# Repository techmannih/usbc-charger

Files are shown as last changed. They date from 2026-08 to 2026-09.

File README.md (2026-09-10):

# USB-C PD 18 W AC Wall Charger

This repository contains the electrical and PCB design for an isolated AC-mains to USB-C Power Delivery charger. Written in tscircuit, the design accepts a nominal 100–240 VAC input and supports three negotiated output profiles: 5 V / 3 A, 9 V / 2 A, and 12 V / 1.5 A, up to 18 W.

The design combines mains protection, EMI filtering, an encapsulated AC/DC module, a USB-PD buck stage, secondary-side transient protection, PCB layout, and a mechanical fit-check enclosure in one TypeScript project.

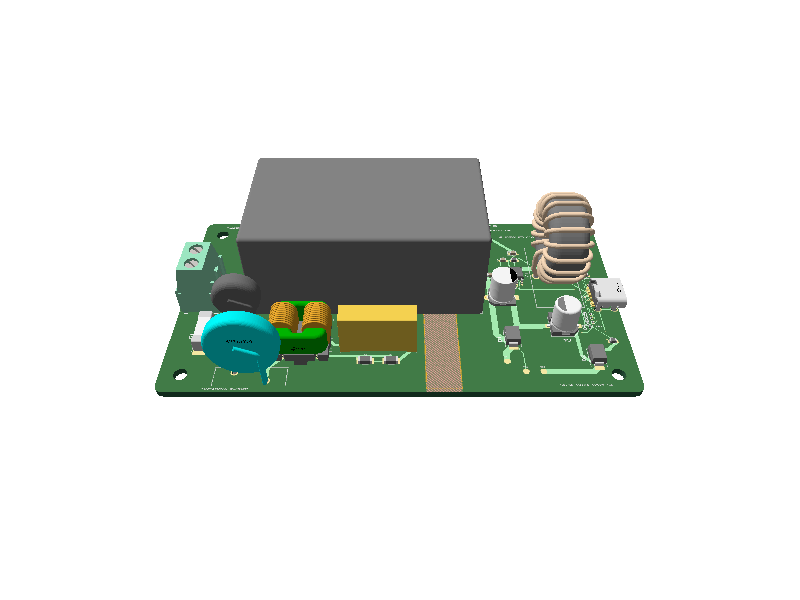
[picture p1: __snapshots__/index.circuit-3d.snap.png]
3D view of the assembled charger PCB


## At a glance

| Item | Specification |
| --- | --- |
| Product input rating | 100–240 VAC, 50/60 Hz |
| AC/DC module operating range | 85–265 VAC |
| USB-C output profiles | 5 V / 3 A, 9 V / 2 A, 12 V / 1.5 A |
| Maximum USB output | 18 W |
| Isolated supply | HLK-20M15C, 15 V / 1.333 A |
| USB-PD buck SoC | Standard Injoinic IP6520 (non-PPS) |
| PCB | 110 × 60 mm, 2-layer, 1.6 mm FR-4 |
| Isolation layout | 8 mm primary-to-SELV all-layer copper keepout |
| Enclosure model | 116 × 66 × 42 mm fit-check shell |
| Firmware | None; the selected IP6520 handles PD negotiation and output selection autonomously |

This implementation uses the standard `IP6520` (`C7433861`) non-PPS variant and is not a USB-C input/sink design. Other IP6520 family variants provide different output profiles and are not approved BOM substitutions.

## Power architecture

```text
AC line / neutral
  │
  ├─ F1      2 A time-delay fuse
  ├─ RV1     300 VAC MOV surge clamp
  ├─ TH1     5 Ω NTC inrush limiter
  ├─ LCM1    two-line common-mode choke
  ├─ C7      305 VAC X2 capacitor with R3/R4 bleeders
  │
  └─ U1      HLK-20M15C isolated 15 V AC/DC module
       │
       ├─ D1 15 V rail TVS
       │
       └─ U2 IP6520 synchronous buck + USB-PD source
            ├─ L1/C4/C5 output power stage
            ├─ D2 USB VBUS TVS
            ├─ D3–D6 CC and USB 2.0 ESD protection
            │
            └─ J2 USB-C output
                 ├─ 5 V / 3 A
                 ├─ 9 V / 2 A
                 └─ 12 V / 1.5 A
```

### Mains input and filtering

The AC input enters through `J1`. The line conductor is protected by a time-delay fuse, MOV, and NTC before passing through the common-mode choke. A safety-rated X2 capacitor filters line-to-neutral noise, while two series bleeder resistors discharge it after disconnection.

The filtered mains input feeds the encapsulated `HLK-20M15C`. Using a bought-out isolated module keeps the carrier board focused on input protection, physical separation, and the low-voltage USB-PD stage instead of implementing a custom offline flyback converter.

### Isolated USB-PD output

The module's isolated 15 V output is locally bypassed and protected by `D1`. The `IP6520` then performs synchronous buck conversion and USB-PD source negotiation. Its switch node drives a 22 µH inductor, output capacitors, and the USB-C VBUS rail.

The USB side includes a dedicated VBUS TVS, individual low-capacitance clamps for CC1, CC2, D+, and D−, and test points for 15 V, ground, and VBUS measurements.

### Power and validation margin

The `HLK-20M15C` is nominally rated for 15 V at 1.333 A. Buck-conversion losses leave little electrical and thermal headroom while delivering the full 18 W USB output. Full-load efficiency, input-current, regulation, and temperature-rise testing in the final closed enclosure are mandatory before retaining the 18 W rating.

The IP6520 input range includes 15 V, but the datasheet's 12 V / 1.5 A electrical-characteristic point is specified with a 24 V input. The exact 15 V input to 12 V / 1.5 A output condition therefore remains a hardware-validation point. If the board cannot sustain it across mains, load, temperature, and transient limits, the 12 V PDO must be removed/derated or the power architecture revised.

## PCB and mechanical design

- Primary-side AC parts are grouped on the left; the isolated USB-PD stage is on the right.
- An 8 mm copper-free corridor spans both copper layers between the primary and SELV regions.
- The ground pour is restricted to the isolated low-voltage side.
- Routed trace widths and via dimensions are recorded in the fabrication geometry report.
- Four 3.2 mm non-plated mounting holes provide fixed enclosure mounting points.
- The USB-C receptacle and mains entry include enclosure aperture definitions.
- The included FDM enclosure is a volume and connector-alignment model, not a production housing.

PCB and schematic snapshots are available in [`__snapshots__/`](__snapshots__). The standalone enclosure fit-check model is in [`mechanical/enclosure-fit-check.scad`](mechanical/enclosure-fit-check.scad).

## Key components

| Ref | Part | Function | JLCPCB/LCSC |
| --- | --- | --- | --- |
| J1 | WJ500V-5.08-2P | AC line/neutral termination | C8465 |
| F1 | SCT1032T2A250V | 2 A / 250 V time-delay fuse | C19712562 |
| RV1 | Bourns MOV-14D471K | 300 VAC surge suppression | C1527439 |
| TH1 | MF72 5D9 | 5 Ω / 3 A inrush limiter | C11277 |
| LCM1 | XRSQ1010-10mH-H | 10 mH two-line common-mode choke | C5380257 |
| C7 | TDK B32922C3104M189 | 100 nF / 305 VAC class-X2 capacitor | C125429 |
| R3, R4 | 1206W4F1004T5E | Series X-capacitor bleeders | C17927 |
| U1 | Hi-Link HLK-20M15C | Isolated 15 V / 1.333 A AC/DC module | C52746093 |
| D1 | SMBJ15A | 15 V rail TVS | C83846 |
| U2 | Injoinic IP6520 | Synchronous buck + USB-PD source SoC; standard non-PPS variant | C7433861 |
| L1 | PDMTAT068125-220MLU | 22 µH buck inductor | C3011539 |
| D2 | SMBJ13A | USB VBUS TVS | C19077567 |
| D3–D6 | PESD5V0H1BSF | CC and USB 2.0 ESD protection | C477989 |
| J2 | TYPE-C-31-M-12 | USB-C receptacle | C165948 |

The supplier IDs are included for design reproducibility, not as an approval of substitutions or a guarantee of stock. Verify the exact manufacturer, rating, footprint, and safety documentation before assembly. In particular, confirm that U2 is marked and ordered as the standard `IP6520`; do not substitute another family variant without requalifying the USB-PD profiles and power budget.

## Repository structure

```text
.
├── index.circuit.tsx              Main tscircuit source and board layout
├── index.circuit.circuit.json     Generated circuit consumed by viewers/tools
├── imports/                       Custom component and footprint definitions
├── firmware/                      Autonomous-controller profile and host PDO checker
├── fabrication/                   BOM, CPL, Gerbers, pin map, drawings and check records
├── scripts/                       Reproducible export and fabrication-integrity checks
├── .github/workflows/             Independent GitHub circuit CI
├── BOM.csv                        Generated complete purchased electrical BOM
├── __snapshots__/                 Schematic, PCB, and 3D reference renders
├── mechanical/                    Enclosure fit-check source
├── FABRICATION_NOTES.md            Board construction and CAM review notes
├── FIRMWARE_BRINGUP.md             Controller/board bring-up; no flashing required
├── PINMAP.md                      Important interfaces and full generated pin-map link
├── POWER_BUDGET.md                Calculated conversion and module headroom
├── JLCPCB_PARTS.md                 Procurement and assembly-list guidance
├── PACKAGE_AUDIT.md                Package and supplier orientation review scope
├── DESIGN_REVIEW.md                Review index and open findings
├── VALIDATION.md                   Reproduction commands and check scope
├── DRC_REPORT.md                   CAD findings and retained-log index
├── COMPLIANCE_PLAN.md             Certification planning and evidence gaps
├── LAB_VALIDATION_PLAN.md         Hardware test plan
├── ENCLOSURE_REQUIREMENTS.md      Production enclosure requirements
└── DESIGN_RISK_REGISTER.md        Known risks and release gates
```

## Getting started

The project uses [Bun](https://bun.sh/) and the tscircuit CLI included in the development dependencies.

```sh
git clone https://github.com/techmannih/usbc-charger.git
cd usbc-charger
bun install
bun run dev
```

`bun run dev` opens the interactive tscircuit development viewer. The default circuit entrypoint is [`index.circuit.tsx`](index.circuit.tsx).

## Commands

| Command | Purpose |
| --- | --- |
| `bun run dev` | Start the interactive local viewer |
| `bun run typecheck` | Check the TypeScript source |
| `bun run check:netlist` | Check declared circuit connections |
| `bun run build` | Build `dist/index/circuit.json` with routing and the parts engine disabled |
| `bun run build:placement` | Alias for the default placement build |
| `bun run build:routed` | Build with full routing, bypassing the placement config; 5-minute timeout per autorouter phase |
| `bun run verify` | Run type, netlist, schematic placement, PCB placement, shorts, and build checks |
| `bun run build:preview` | Generate PCB, schematic, and 3D preview images |
| `bun run snapshot:update` | Update committed PCB, schematic, and 3D snapshots |
| `bun run snapshot:3d:update` | Update the committed angled 3D snapshot |
| `bun run build:handoff` | Generate KiCad, STEP, and GLB handoff outputs |
| `bun run export:fabrication` | Fresh build, check records, BOM/CPL/pinmap, both schematic sheets and gated Gerber export |
| `bun run check:fabrication` | Verify generated artifacts, BOM/placement coverage, archive contents and source hashes |
| `bun run check:pdos <capture.json>` | Compare decoded analyzer PDOs with the design targets; no device flashing |

Generated export files are written under `dist/index/`.

`tscircuit.config.json` disables routing for the default build, including hosted
builds that read this config. Use `bun run build:routed` for routed output.
CI, `verify`, handoff builds, and fabrication exports explicitly enable routing.

The dedicated fabrication workflow writes a versioned review package under
[`fabrication/`](fabrication/README.md), plus the root [`BOM.csv`](BOM.csv).
It requires Bun and `zip`/`unzip`. Its source inventory and file hashes prevent
accidental mixing of revisions. See
[`REFERENCE_COMPARISON.md`](fabrication/REFERENCE_COMPARISON.md) for the file-category
mapping to the three linked pedometer projects.

The controller needs no external application firmware. The new
[`firmware/`](firmware/README.md) folder records the expected fixed PDOs and
contains a host-side capture checker. It cannot change U2's behavior.

## Development workflow

Use a topic branch and open a pull request into `main`, with a descriptive
commit/PR title such as `ci: add circuit build checks`. The
[`Circuit CI`](.github/workflows/circuit-ci.yml) workflow runs on pull requests
into `main`, pushes to `main`, and manual dispatches. It provides three checks:
`Typecheck`, `Netlist`, and `Build`. Build waits for both other checks, verifies
the committed fabrication package, compiles the circuit, then checks the fresh
routed output for copper shorts. Build outputs and any short-check diagnostics
are retained as a workflow artifact for seven days.

CI uses Bun 1.3.14 from `packageManager`, SHA-pinned actions, a frozen lockfile,
and read-only repository permissions. It does not publish to tscircuit, push
commits, or approve manufacturing. Existing placement-review findings remain
documented in [`DRC_REPORT.md`](DRC_REPORT.md); this workflow is not the full
`bun run verify` release gate. To enforce checks before merge, configure the
three check names as required in GitHub branch rules after their first run.

The package version is `1.0.10`, which was unused in the tscircuit registry when
checked on September 10, 2026. Hosted `1.0.9` already belongs to commit `6e64034`;
the integration skips a different commit that reuses that release version.
Use an unused version when pushing the next hosted release.

The `1.0.9` hosted build completed with exit code 0 and uploaded its outputs,
but its GitHub `tscircuit/build` status was absent. The later `dabd400` push was
accepted by the webhook but produced no new release. A version bump addresses
the release collision; missing GitHub status updates require a separate check
of tscircuit's integration permissions and server-side status-update logs.
Verify both the release commit and the GitHub status after pushing to `main`
(or merging a PR). A passing `Circuit CI` result alone does not establish either.

Regenerate `bun run export:fabrication` and run `bun run check:fabrication`
after changing files covered by the fabrication manifest, including
`package.json`, documentation, or export scripts; commit the refreshed outputs
with those changes.

After changing the circuit source or a component definition:

```sh
bun run verify
bun run snapshot:update
bun run snapshot:3d:update
git diff -- index.circuit.circuit.json __snapshots__
```

Commit `index.circuit.circuit.json` whenever the TSX circuit changes. Hosted viewers and downstream tools can consume this generated file; leaving it stale can make a deployed board differ from the local `tsci dev` render.

Before opening a hardware or manufacturing handoff, inspect the schematic, PCB, 3D assembly, generated circuit JSON, and check outputs together.

## Design status

The repository contains the CAD source and engineering workflow for a hardware prototype. It is not a validated or certified consumer product. Automated CAD checks establish source consistency; they do not prove electrical safety, EMC performance, thermal margin, enclosure safety, or USB-IF compliance.

The remaining physical work includes:

- prototype assembly and incoming-part verification;
- USB-PD protocol and load testing across every supported PDO;
- efficiency, ripple, thermal-rise, and abnormal-condition testing;
- surge, EFT, ESD, conducted/radiated emissions, and immunity testing;
- creepage, clearance, dielectric-strength, leakage, and accessible-part evaluation;
- validation inside the final flame-retardant enclosure with the production cord and strain relief.

See the project handoff documents for detailed requirements:

- [`COMPLIANCE_PLAN.md`](COMPLIANCE_PLAN.md)
- [`LAB_VALIDATION_PLAN.md`](LAB_VALIDATION_PLAN.md)
- [`ENCLOSURE_REQUIREMENTS.md`](ENCLOSURE_REQUIREMENTS.md)
- [`DESIGN_RISK_REGISTER.md`](DESIGN_RISK_REGISTER.md)

## Safety notice

This board contains hazardous mains voltage. Do not energize an exposed PCB, connect it to a phone, or treat the fit-check enclosure as a finished product. Mains testing and enclosure review must be performed with appropriate equipment by qualified personnel.

The final product requires verified safety-critical parts, a rated cable and plug, independent strain relief, inaccessible live parts, preserved creepage and clearance, a suitable flame-retardant enclosure, and approval under the standards applicable to the target market.

## Design references

- [Hi-Link HLK-20M15C product page](https://www.hlktech.net/index.php?cateid=734&id=128)
- [Injoinic IP6520 datasheet](https://www.injoinic.com/api/static/uploads/20250529/20250529105252_6837cc049d55b.pdf)
- [TDK B32922C3104M189 X2 capacitor](https://product.tdk.com/en/search/capacitor/film/emi-suppression/info?part_no=B32922C3104M189)
- [Bourns MOV-14D series datasheet](https://www.bourns.com/docs/Product-Datasheets/MOV14D.pdf)
- [USB-IF USB Type-C and USB Power Delivery](https://www.usb.org/usbc)
- [USB-IF compliance program](https://www.usb.org/compliance)
- [BIS products under compulsory registration](https://www.bis.gov.in/product-certification/products-under-compulsory-certification/scheme-ii-registration-scheme/)

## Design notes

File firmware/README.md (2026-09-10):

# Firmware and controller configuration

This board has no programmable microcontroller, external flash, SWD/JTAG header,
UART console or I²C configuration interface. U2 is the standard non-PPS IP6520
power-conversion/PD source controller. No application binary needs to be built
or flashed for this hardware revision. The pedometer references use an MCU,
BLE and sensors; their firmware cannot run on this charger.

[`expected-pdos.json`](expected-pdos.json) records the design targets from the
main schematic and the exact U2 ordering variant. Editing it does not change
the controller's output behavior. Changing advertised PDOs requires a reviewed
controller/variant or hardware change, followed by hardware verification.

## Files

| File | Purpose |
| --- | --- |
| `expected-pdos.json` | Expected 5 V / 3 A, 9 V / 2 A and 12 V / 1.5 A fixed PDOs |
| `check-pdos.mjs` | Host-side check of decoded protocol-analyzer records |
| `VALIDATION.md` | Software-check scope and hardware evidence status |
| `../FIRMWARE_BRINGUP.md` | Board bring-up, interfaces and observation points |

## Check a protocol capture

Export/decode the analyzer's Source_Capabilities message and map it to this JSON
schema. This is a schema example, not a measured capture; replace the metadata
and PDO values with the actual observation. Keep the original analyzer log.

```json
{
  "schema_version": 1,
  "sample_id": "REPLACE_WITH_ASSEMBLED_SAMPLE_ID",
  "analyzer": "REPLACE_WITH_ANALYZER_MODEL_AND_SERIAL",
  "captured_at": "2026-09-10T00:00:00Z",
  "evidence_file": "REPLACE_WITH_ORIGINAL_ANALYZER_LOG_PATH",
  "source_capabilities": [
    { "type": "fixed", "voltage_v": 5, "current_a": 3 },
    { "type": "fixed", "voltage_v": 9, "current_a": 2 },
    { "type": "fixed", "voltage_v": 12, "current_a": 1.5 }
  ]
}
```

```sh
bun run check:pdos /path/to/capture.json
```

The checker requires the three exact PDOs in the order shown and rejects extra
PDOs/APDOs, wrong types, missing metadata and wrong advertised current/voltage.
It checks the supplied decoded record; it does not authenticate the evidence
file, connect to an analyzer, measure VBUS, test regulation or certify USB-PD.

Reference: [Injoinic IP6520 datasheet linked by this design](https://www.injoinic.com/api/static/uploads/20250529/20250529105252_6837cc049d55b.pdf).
Confirm the standard variant's ordering table; the family contains different
PPS and power-profile variants.

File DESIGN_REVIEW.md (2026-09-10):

# Design review

The current implementation is an 18 W, two-layer isolated mains charger with
an HLK-20M15C 15 V supply and standard non-PPS IP6520 output controller.
The reference pedometers provide examples of repository organization; their
BLE, battery-charger, sensor, MCU and RF design details do not apply here.

## Review artifacts

| Review area | Evidence / document |
| --- | --- |
| Architecture, ratings and source | `README.md`, `index.circuit.tsx` |
| Pin/net correspondence | `PINMAP.md`, `fabrication/PINMAP.csv`, `fabrication/netlist.txt` |
| Procurement and assembly | `BOM.csv`, `JLCPCB_PARTS.md`, fabrication BOM/CPL/manual list |
| Package/centroid verification | `PACKAGE_AUDIT.md`, `fabrication/placement-review.csv` |
| Output power and thermal headroom | `POWER_BUDGET.md`, `DESIGN_RISK_REGISTER.md` |
| Controller bring-up | `FIRMWARE_BRINGUP.md`, `firmware/` |
| Automated CAD validation | `VALIDATION.md`, `DRC_REPORT.md`, `fabrication/checks/` |
| Construction and physical tests | Existing compliance, enclosure and lab plans |

## Open findings

The design needs measured verification at 18 W, especially 12 V / 1.5 A from
the 15 V module rail. Supplier orientation/centroid calibration and a physical
footprint audit remain open. The existing placement checker reports orientation
suggestions for C6, D5 and D6; schematic placement also reports readability
suggestions. Their exact outputs are retained with the package.

The fabrication workflow checks routed copper separately from source
connectivity and records source hashes so files from different revisions can
be detected. It keeps the existing hardware validation gates visible and does
not turn a successful CAD check into a production release.

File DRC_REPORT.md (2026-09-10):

# CAD check report

Authoritative results for the current exported artifact are in
[`fabrication/validation.json`](fabrication/validation.json) and
[`fabrication/checks/`](fabrication/checks/). Regenerate them after source changes.

The initial assessment for this file-package addition found:

- netlist check: no errors or warnings;
- routed-circuit checks: no findings;
- Gerber-derived shorts check: no detected shorts;
- PCB placement: three suboptimal-orientation suggestions (C6, D5, D6),
  with zero placement DRC errors/warnings; the command exits 1 for the suggestions;
- schematic placement: existing orientation/trace-simplification suggestions;
- build: succeeds with existing courtyard, chip pin-specification and
  schematic-reference diagnostics.

The build's reference-text warnings include built-in symbols whose labels are
drawn by the renderer. Both schematic sheets are exported for visual review.
Warnings are retained in `checks/build.log`, not silently counted as passes.

These findings do not constitute supplier CAM or physical clearance approval.
The export gate requires no routed-artifact errors and a passing copper-shorts
check. The manifest remains `released_for_manufacturing: false` until the
separate design, assembly and hardware release process is completed.

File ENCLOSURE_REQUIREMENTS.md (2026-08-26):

# Production enclosure requirements

The `enclosure.fdm.box` in the circuit is a 116 × 66 × 42 mm fit-check shell. It is suitable for checking connector alignment and board volume only. Do not use a hobby FDM print as the consumer mains enclosure.

The production mechanical design must be reviewed with the safety lab and should include:

- a certified/traceable flame-retardant insulating resin and process appropriate to the applicable standard, with material documentation retained per production lot;
- no user-accessible primary conductor, terminal, screw, solder joint or mounting hardware under accessibility probes and expected deformation;
- a rated two-core mains lead and plug for the destination market, with double-insulated internal wiring and a listed cable gland/strain relief sized to the real cord;
- independent cord anchorage so a pull or twist cannot load J1 or reduce primary-to-SELV spacing;
- insulating ribs/barriers and standoff geometry that preserve required creepage/clearance after assembly tolerances, solder protrusion, impact and heat;
- captive/secure board retention using the four 3.2 mm non-plated holes without conductive hardware bridging insulation zones;
- a USB-C opening that cannot expose internal live parts and does not mechanically overload J2;
- ventilation only if the lab accepts it; openings must still pass accessibility and fire-containment requirements;
- tamper-resistant closure, adequate impact strength and no service access for ordinary users;
- permanent external ratings, model/serial traceability, indoor-use/safety markings and certification identifiers only after authorization.

## Mechanical release checks

- Import the actual PCB STEP output and exact bought-out connector/cord models into production CAD.
- Apply dimensional, molding/shrink and assembly tolerance stacks to apertures, standoffs and insulation barriers.
- Verify assembly sequence, no pinched wires, strain-relief engagement, fastener torque and repeatable connector location.
- Conduct thermal testing in the real color, resin, wall thickness and closed configuration; the fit-check shell is not a thermal surrogate.
- Freeze the enclosure drawing, resin grade, molder/process and cord assembly as certification-controlled items.

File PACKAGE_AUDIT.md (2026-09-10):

# Footprint and package audit

This document identifies package checks for the current imports. It records
the review scope; it is not a completed manufacturer-drawing audit.

| Parts | Source / check |
| --- | --- |
| U1 | `imports/HLK_20M15C.tsx`: module pin numbering, 15 V polarity, body and lead clearance |
| U2 | `imports/IP6520.tsx`: ESOP8/EP pin 9, exposed-pad dimensions and thermal-via process |
| J1 | `imports/WJ500V_5_08_2P.tsx`: 5.08 mm terminals, AC neutral alias, cable access |
| J2 | `imports/TYPE_C_31_M_12.tsx`: 16 selectors, duplicated contacts, SMT land pattern, plated slots and NPTH locating holes |
| LCM1 | `imports/XRSQ1010_10mH_H.tsx`: winding pairs, four lead positions and full body outline |
| L1 | `imports/PDMTAT068125_220MLU.tsx`: actual through-hole package and body orientation |
| C7 | `imports/B32922C3104M189.tsx`: lead spacing and safety-rated body |
| C1/C4 | Imported SMT can footprints: pin-1 polarity and supplier centroid |
| D1/D2 | Imported SMB packages: cathode pad and diode orientation |
| D3–D6 | Imported tiny ESD package: land sizes, pad spacing, stencil and rotation |
| Small R/C parts | Built-in 0603/1206 footprints: land pattern versus exact purchased part |
| F1/RV1/TH1 | Imported footprints: body size, pad/lead form, heat and clearance requirements |

The source carries MPN/supplier IDs, footprint geometry and 3D-model URLs. A
model URL or successful render is not proof that the physical part matches.
Compare manufacturer package drawings with pads, hole dimensions, pin map,
body/courtyard and mechanical fit. Record differences before approving changes.

Generated [`geometry.json`](fabrication/geometry.json) and
[`placement-review.csv`](fabrication/placement-review.csv) support this review.
STEP/GLB models can be regenerated using `bun run build:handoff`; inspect any
reported missing-model downloads separately.

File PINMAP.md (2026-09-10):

# Pin and interface map

The complete map is generated at [`fabrication/PINMAP.csv`](fabrication/PINMAP.csv)
from the same circuit JSON used for the manufacturing review exports. It
includes aliases, physical pad coordinates, layer sets and intentional NCs.

## U2: standard IP6520

| Pin | Signal | Board net |
| --- | --- | --- |
| 1 | VOUT | VBUS_OUT |
| 2 | VIN | VIN_15V |
| 3 | SW | SW |
| 4 | BST | BST |
| 5 | DM | USB_DM |
| 6 | DP | USB_DP |
| 7 | CC1 | CC1 |
| 8 | CC2 | CC2 |
| 9 | Exposed pad / GND | GND |

## U1: isolated module

| Pin | Signal | Board net |
| --- | --- | --- |
| 1 | AC2 | AC_N_FILTERED |
| 2 | AC1 | AC_L_FILTERED |
| 3 | VNEG | GND |
| 4 | VPOS | VIN_15V |

## J2: USB-C connector

The import numbers 1–16 are footprint selectors, not USB Type-C contact names.
Use the aliases in PINMAP.csv: pin 6 = A5/CC1, pin 12 = B5/CC2;
pins 8/10 = A6/B6/D+, pins 9/7 = A7/B7/D−;
pins 15/16 = B4A9/A4B9/VBUS, pins 13/14 = A1B12/B1A12/GND.
Pins 1–4 are shield tabs. Pins 5/11 (B8/A8, SBU2/SBU1) are intentionally NC.

J1 pin 2 has the imported alias `GND` but belongs to **AC_N**. It is not
connected to the isolated low-voltage ground. TP1, TP2 and TP3 are respectively
VIN_15V, isolated GND and VBUS_OUT.

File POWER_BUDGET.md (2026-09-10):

# Power budget

These calculations use the design's nominal U1 rating of 15 V × 1.333 A =
19.995 W. They are estimates, not measured efficiency or thermal results.

| USB fixed PDO target | Output power | U1 current at 90% buck efficiency | U1 current at 95% buck efficiency |
| --- | --- | --- | --- |
| 5 V / 3 A | 15 W | 1.111 A | 1.053 A |
| 9 V / 2 A | 18 W | 1.333 A | 1.263 A |
| 12 V / 1.5 A | 18 W | 1.333 A | 1.263 A |

`I_U1 = P_USB / (15 V × buck efficiency)`. At 18 W, a nominal 90% conversion
efficiency consumes essentially all of the module's rated output. Even at
95%, only about 1.05 W remains at the module output before accounting for
derating and other losses. Required conversion efficiency at the nominal
module limit is about `18 / 19.995 = 90.02%`.

The input/EMI losses and U1 AC/DC losses add heat and affect overall wall-to-USB
efficiency. They are not included in the buck-only calculation above. Thermal
derating can further reduce the usable 19.995 W module rating.

At the 12 V PDO, nominal input-to-output voltage difference is only 3 V. Verify
dropout, ripple and load transients at the actual minimum 15 V rail. The
datasheet electrical-characteristic point for 12 V / 1.5 A uses 24 V input, so
it is not evidence of measured performance for this board's 15 V input.

## Measurements to retain

Record AC input power, U1 rail voltage/current, USB voltage/current, ambient,
steady-state temperatures and enclosure revision at each PDO and declared
input extreme. Use [`LAB_VALIDATION_PLAN.md`](LAB_VALIDATION_PLAN.md) for the
test scope. No thermal or efficiency measurements have been supplied.

The project name's historic `20w` directory does not change the implemented
18 W target. Exact controller identity and target profiles are in
[`firmware/expected-pdos.json`](firmware/expected-pdos.json).

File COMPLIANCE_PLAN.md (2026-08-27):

# Compliance plan

Status: engineering-validation design; no certification, registration, licence, TID or logo authorization has been obtained.

This plan must be frozen against the exact PCB revision, BOM, firmware/silicon revision, mains cord/plug and final enclosure submitted to the labs. A change to any safety-critical item can require review or retest.

## Intended product definition

- External Class II power adaptor for IT/consumer equipment.
- Label input: 100–240 VAC, 50/60 Hz. The AC/DC module's 85–265 VAC figure is an operating range, not the proposed consumer label range.
- USB-C source PDOs: 5 V/3 A, 9 V/2 A and 12 V/1.5 A; 18 W maximum; exact standard IP6520 non-PPS variant.
- No protective-earth connection.
- Final construction: closed, touch-safe, flame-retardant enclosure with a rated mains cord/plug and strain relief.

## Workstream matrix

| Workstream | Design evidence available | Required independent evidence before sale |
| --- | --- | --- |
| India electrical safety | Isolated module architecture, fused/protected input, primary/SELV keepout, controlled BOM | BIS-recognized lab report and registration for the final adaptor under the classification/standard confirmed by BIS; construction, dielectric, temperature and abnormal-condition results |
| International electrical safety | Hazard-based design provisions and component documentation | Accredited evaluation to the applicable market edition, commonly IEC 62368-1 or its national adoption; national deviations and marking review |
| USB Type-C/PD | Standard non-PPS IP6520 reference topology and fixed-supply PDO intent | USB-IF-authorized lab execution of every applicable Type-C and PD CTS section; valid TID/listing before using certified USB claims or logos |
| EMC/immunity | CMC, X2 capacitor, local bypassing, short power loops and port ESD parts | Conducted/radiated emissions and applicable ESD, EFT, surge, dips/interruptions and immunity tests on the final closed product |
| Energy efficiency | Low-power topology selected | Applicable market efficiency/no-load measurements and declarations for external power supplies |
| Materials/mechanics | Mounting holes and fit-check enclosure model | Resin flammability evidence, touch-access/probe tests, impact/drop, cord anchorage, torque, heat/ball-pressure and enclosure construction review |
| Production conformity | Exact MPNs and supplier numbers recorded | Approved-vendor list, incoming inspection, traceability, calibrated end-of-line tests and controlled change process |

## India submission package

Prepare at minimum:

- final schematic, PCB artwork/stack-up, critical-component list and BOM;
- component certificates/datasheets for the AC/DC module, fuse, MOV, X2 capacitor, PCB laminate, enclosure resin, connector and mains lead/plug;
- photographs and construction drawings showing insulation barriers, spacings, internal wiring, strain relief and markings;
- product label artwork, model/series declaration and user safety instructions;
- risk assessment, abnormal-condition rationale and production test procedure;
- samples that exactly match the declared PCB, enclosure and critical BOM.

India's current BIS material lists “Power Adaptors for IT Equipments” under IS 13252 (Part 1):2010. The published uniform test report references amendments A1:2013 and A2:2015. The applicant/lab must verify the current classification and amendments at submission time; do not print a BIS standard mark or registration number before grant.

## Change control

Treat these as certification-affecting changes: AC/DC module source or construction, PCB layout in the mains/isolation region, fuse or MOV rating, X/Y safety capacitor, enclosure material/wall geometry, mains cord/plug/strain relief, USB-PD buck SoC variant or supported PDOs. Other IP6520 family variants are not approved substitutions for the standard non-PPS `IP6520`. Record the rationale and obtain lab/certification-body disposition before production.

## Authoritative starting points

- [BIS Scheme II compulsory-registration products](https://www.bis.gov.in/product-certification/products-under-compulsory-certification/scheme-ii-registration-scheme/)
- [BIS power-adaptor uniform test report](https://www.bis.gov.in/PDF/UTRFs/FINALIZED_TRF_IS_13252_A1_A2_Power_Adaptor_for_IT_Equipment_V1_3.pdf)
- [MeitY series guidelines](https://www.meity.gov.in/sites/upload_files/dit/files/Revised_SeriesGuideline.pdf)
- [IEC 62368-1:2023 publication](https://webstore.iec.ch/en/publication/20471)
- [USB-IF USB Type-C/PD compliance overview](https://www.usb.org/usbc)
- [USB-IF compliance program](https://www.usb.org/compliance)
- [USB Power Delivery Compliance Test Specification](https://www.usb.org/document-library/usb-power-delivery-compliance-test-specification-0)

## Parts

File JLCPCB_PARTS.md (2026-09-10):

# Supplier parts and BOM

[`BOM.csv`](BOM.csv) is the complete purchased electrical BOM, generated from
source MPNs and JLCPCB/LCSC IDs. [`fabrication/BOM-SMT.csv`](fabrication/BOM-SMT.csv)
is the subset matching the SMT placement file. Through-hole and mixed parts
are listed in [`fabrication/manual-assembly.csv`](fabrication/manual-assembly.csv).

Supplier stock, price, basic/extended tier and assembly availability have not
been checked in this handoff. The exporter uses local footprints and does not
replace the source's part identities using live supplier data.

## Ordering constraints

- U2 must be standard non-PPS `IP6520`, `C7433861`. Other IP6520 variants are
  not approved equivalents just because the package matches.
- C7 is the specified class-X2 part; generic 100 nF capacitors are not substitutes.
- Verify exact fuse, MOV, NTC and AC/DC module ratings and documentation.
- Retain electrolytic polarity and voltage rating: C1 = 100 µF / 35 V,
  C4 = 100 µF / 25 V.
- L1 is `PDMTAT068125-220MLU`, a through-hole part in this import; verify its
  real package, electrical rating and envelope before order.
- TP1–TP3 and H1–H4 are PCB features, excluded from procurement/CPL.

The all-parts BOM is useful for procurement; upload the SMT subset only when
requesting SMT assembly. Quote the manual/mixed list separately with the
assembler. External cable, plug, gland, mounting hardware and production
enclosure need their own mechanical purchasing list.

An updated supplier quote or substitution review should identify the source
manifest, reviewer, date, approved MPN/LCSC identity and verified supplier
rotation. No such approvals are implied by the generated CSVs.

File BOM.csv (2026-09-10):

Comment | Designator | Footprint | LCSC Part # | Quantity | Manufacturer Part Number | Assembly
100uF 35V RVE100UF35V67RV0072 | C1 | RVE100UF35V67RV0072 (SMT; 2 SMT pads; 0 PTH) | C2836437 | 1 | RVE100UF35V67RV0072 | SMT
100nF 50V CC0603KRX7R9BB104 | C2,C5 | CC0603KRX7R9BB104 (SMT; 2 SMT pads; 0 PTH) | C14663 | 2 | CC0603KRX7R9BB104 | SMT
2.2uF 25V GRM188Z71E225KE43D | C3 | GRM188Z71E225KE43D (SMT; 2 SMT pads; 0 PTH) | C415535 | 1 | GRM188Z71E225KE43D | SMT
100uF 25V RVT1E101M0607 | C4 | RVT1E101M0607 (SMT; 2 SMT pads; 0 PTH) | C72477 | 1 | RVT1E101M0607 | SMT
1nF 50V GRM1885C1H102JA01D | C6 | GRM1885C1H102JA01D (SMT; 2 SMT pads; 0 PTH) | C77026 | 1 | GRM1885C1H102JA01D | SMT
100nF 305V B32922C3104M189 | C7 | B32922C3104M189 (through-hole; 0 SMT pads; 2 PTH) | C125429 | 1 | B32922C3104M189 | through-hole
SMBJ15A | D1 | SMBJ15A (SMT; 2 SMT pads; 0 PTH) | C83846 | 1 | SMBJ15A | SMT
SMBJ13A | D2 | SMBJ13A (SMT; 2 SMT pads; 0 PTH) | C19077567 | 1 | SMBJ13A | SMT
PESD5V0H1BSF | D3,D4,D5,D6 | PESD5V0H1BSF (SMT; 2 SMT pads; 0 PTH) | C477989 | 4 | PESD5V0H1BSF | SMT
2A / 250V SCT1032T2A250V | F1 | SCT1032T2A250V (SMT; 2 SMT pads; 0 PTH) | C19712562 | 1 | SCT1032T2A250V | SMT
WJ500V-5.08-2P | J1 | WJ500V-5.08-2P (through-hole; 0 SMT pads; 2 PTH) | C8465 | 1 | WJ500V-5.08-2P | through-hole
TYPE-C-31-M-12 | J2 | TYPE-C-31-M-12 (mixed; 12 SMT pads; 4 PTH) | C165948 | 1 | TYPE-C-31-M-12 | mixed
22µH PDMTAT068125-220MLU | L1 | PDMTAT068125-220MLU (through-hole; 0 SMT pads; 2 PTH) | C3011539 | 1 | PDMTAT068125-220MLU | through-hole
XRSQ1010-10mH-H | LCM1 | XRSQ1010-10mH-H (through-hole; 0 SMT pads; 4 PTH) | C5380257 | 1 | XRSQ1010-10mH-H | through-hole
2Ω FRC0603F2R00TS | R1 | FRC0603F2R00TS (SMT; 2 SMT pads; 0 PTH) | C2933191 | 1 | FRC0603F2R00TS | SMT
0Ω 0603WAF0000T5E | R2 | 0603WAF0000T5E (SMT; 2 SMT pads; 0 PTH) | C21189 | 1 | 0603WAF0000T5E | SMT
1MΩ 1206W4F1004T5E | R3,R4 | 1206W4F1004T5E (SMT; 2 SMT pads; 0 PTH) | C17927 | 2 | 1206W4F1004T5E | SMT
MOV-14D471K | RV1 | MOV-14D471K (through-hole; 0 SMT pads; 2 PTH) | C1527439 | 1 | MOV-14D471K | through-hole
MF72 5D9 | TH1 | MF72 5D9 (through-hole; 0 SMT pads; 2 PTH) | C11277 | 1 | MF72 5D9 | through-hole
HLK-20M15C | U1 | HLK-20M15C (through-hole; 0 SMT pads; 4 PTH) | C52746093 | 1 | HLK-20M15C | through-hole
IP6520 | U2 | IP6520 (SMT; 9 SMT pads; 0 PTH) | C7433861 | 1 | IP6520 | SMT

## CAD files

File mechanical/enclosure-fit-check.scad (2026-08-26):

/*
  USB-C PD charger enclosure — DIMENSIONAL FIT CHECK ONLY.

  This is not a certified, flame-safe or production-ready mains enclosure.
  Final material, wall/rib geometry, cord anchorage, accessibility and thermal
  performance require review and testing by the product safety laboratory.

  Set part to "base", "lid" or "assembly" before exporting an STL/3MF.
*/

$fn = 48;
part = "assembly";

board_x = 110;
board_y = 60;
board_z = 1.6;
outer_x = 116;
outer_y = 66;
base_z = 40;
wall = 2;
lid_z = 2;
corner_r = 2;

standoff_h = 3;
standoff_od = 7;
mount_hole = 3.2;
mount_clearance = 0.25;
mount_xy = [[-50, -25], [-50, 25], [50, -25], [50, 25]];

pcb_floor_z = wall + standoff_h;
port_center_z = pcb_floor_z + board_z + 1.7;
cable_hole_d = 9;
usb_cutout_y = 10.5;
usb_cutout_z = 4.5;

module rounded_xy_box(size, radius) {
  linear_extrude(height = size[2], center = true)
    offset(r = radius)
      square([size[0] - 2 * radius, size[1] - 2 * radius], center = true);
}

module pill_2d(length, height) {
  hull() {
    translate([-(length - height) / 2, 0]) circle(d = height);
    translate([(length - height) / 2, 0]) circle(d = height);
  }
}

module base_shell() {
  difference() {
    translate([0, 0, base_z / 2])
      rounded_xy_box([outer_x, outer_y, base_z], corner_r);

    // Open-top internal cavity; the bottom wall remains intact.
    translate([0, 0, wall + (base_z - wall + 0.2) / 2])
      rounded_xy_box(
        [outer_x - 2 * wall, outer_y - 2 * wall, base_z - wall + 0.2],
        max(corner_r - wall / 2, 0.5)
      );

    // Left-wall cable-gland pilot aperture.
    translate([-outer_x / 2 - 0.1, 0, port_center_z])
      rotate([0, 90, 0]) cylinder(d = cable_hole_d, h = wall + 0.2);

    // Right-wall USB-C pill aperture.
    translate([outer_x / 2 - wall - 0.1, 0, port_center_z])
      rotate([0, 90, 0])
        linear_extrude(height = wall + 0.2)
          rotate(90) pill_2d(usb_cutout_y, usb_cutout_z);
  }

  // Four standoffs match the PCB's non-plated mounting holes.
  for (xy = mount_xy) {
    translate([xy[0], xy[1], wall])
      difference() {
        cylinder(d = standoff_od, h = standoff_h);
        cylinder(d = mount_hole + mount_clearance, h = standoff_h + 0.1);
      }
  }
}

module lid() {
  union() {
    translate([0, 0, lid_z / 2])
      rounded_xy_box([outer_x, outer_y, lid_z], corner_r);

    // Loose locating lip for fit checks; not a certified closure method.
    translate([0, 0, -1])
      difference() {
        rounded_xy_box([outer_x - 2 * wall - 0.4, outer_y - 2 * wall - 0.4, 2], 1);
        rounded_xy_box([outer_x - 4 * wall, outer_y - 4 * wall, 2.2], 0.5);
      }
  }
}

module pcb_mockup() {
  color([0.05, 0.35, 0.2, 0.55])
    translate([0, 0, pcb_floor_z + board_z / 2])
      cube([board_x, board_y, board_z], center = true);
}

if (part == "base") {
  base_shell();
} else if (part == "lid") {
  lid();
} else {
  color([0.75, 0.75, 0.78, 0.65]) base_shell();
  pcb_mockup();
  color([0.85, 0.85, 0.88, 0.45])
    translate([0, 0, base_z + 8]) lid();
}

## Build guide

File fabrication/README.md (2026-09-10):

# Charger fabrication package

Generated from `index.circuit.tsx` by `bun run export:fabrication`.
This directory is intentionally versioned so the files are visible alongside
the source in repository and tscircuit file browsers.

| File | Contents |
| --- | --- |
| `BOM.csv` | Complete grouped purchased-parts BOM; same as root `BOM.csv` |
| `BOM-SMT.csv` | BOM subset corresponding exactly to `CPL.csv` |
| `CPL.csv` | SMT component centres and native CAD rotations |
| `manual-assembly.csv` | Through-hole and mixed-technology components to fit |
| `PINMAP.csv` | Every source pin, net, aliases and physical pad coordinates |
| `placement-review.csv` | All purchased parts, process and orientation review status |
| `Gerbers.zip` | Copper, mask, paste, silkscreen, outline and Excellon drill files |
| `gerbers/` | Same CAM files unpacked for inspection |
| `pcb.svg`, `assembly.svg` | PCB and assembly review drawings |
| `schematic-mains.svg`, `schematic-pd.svg` | Both schematic sheets |
| `netlist.txt`, `circuit.json` | Readable netlist and exact export input |
| `geometry.json` | Measured geometry inventory and export coordinate convention |
| `validation.json`, `checks/` | Check outcomes and retained command logs |
| `manifest.json` | Source, tool and artifact SHA-256 provenance |
| `ASSEMBLY_REQUIREMENTS.md` | Assembly process, polarity and part checks |
| `REFERENCE_COMPARISON.md` | Mapping from the three reference pedometer projects |

The archive is produced only after the current artifact's routing and copper
shorts checks pass. Review `validation.json` for all other issues; an available
Gerber archive does not indicate a production release. If a later run fails
the gate, the previous archive is moved into ignored `dist/fabrication-obsolete/`
and excluded from the current manifest.

All coordinates use mm, board-centre origin, +Y up and CCW degrees. CPL includes
only pure SMT purchased parts. Fit the parts in `manual-assembly.csv` too;
J2's electrical contacts are SMT while its shell tabs are plated holes.

The exporter replaces only its own generated outputs. Keep hand-maintained
notes in Markdown. Regenerate after changing the circuit, imports, toolchain,
firmware targets or export scripts; `bun run check:fabrication` detects stale
sources and mismatched artifacts.

For optional STEP, GLB and KiCad outputs, use `bun run build:handoff`; these
remain under ignored `dist/index/` because they are large and can depend on
remote component models. Regenerate them from the current source before use.

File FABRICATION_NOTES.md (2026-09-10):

# Fabrication notes

Use [`fabrication/README.md`](fabrication/README.md) as the file index. The
export is an engineering review package for this 18 W charger revision.
`manifest.json` records the exact source, circuit, tool versions and file hashes;
`validation.json` records automated results and outstanding reviews.

## Board construction

| Parameter | Current design |
| --- | --- |
| Outline | 110 × 60 mm, 2 mm rounded corners |
| Layers / thickness / material | Two copper layers / 1.6 mm / FR-4 |
| Solder mask | Green (`#176b43`) |
| Mounting | Four Ø3.2 mm NPTHs, at (±50, ±25) mm |
| Coordinate origin | Board centre, mm; +X right, +Y up; rotations CCW |
| Primary / isolated boundary | All-layer copper keepout, x = 6…14 mm |
| Copper weight / finish / panel | To be agreed with fabricator; not specified by the current TSX |

The minimum geometry actually present is reported by the exporter. The board's
generic CAD minima are not mains spacing requirements. Inspect copper, drill
files and assembled parts together at the isolation boundary. Keep the ground
pour on the isolated side.

## CAM and assembly review

Check outline dimensions, PTH versus NPTH drilling, J2 plated slots, hole sizes,
annular rings, mask openings and paste before fabrication. The four U2 thermal
vias are Ø0.25 mm drills in Ø0.55 mm pads inside its exposed pad; agree the
via-in-pad and stencil process with the assembler. Auto-routed vias may use
different dimensions; inspect `geometry.json` for measured minima.

`CPL.csv` contains surface-mount placements only. Through-hole parts and the
mixed SMT/PTH USB connector are listed separately in `manual-assembly.csv`.
Their omission from CPL is an assembly-process decision, not a DNP instruction.
TP1–TP3 are bare copper pads; H1–H4 are drilled features, not purchased parts.
See [`ASSEMBLY_REQUIREMENTS.md`](fabrication/ASSEMBLY_REQUIREMENTS.md).

Positions are native CAD component centres, with no Y-axis flip or supplier
rotation correction. A fabricator's pin-1/centroid preview must be reviewed for
every placement. Do not assume CAD rotation zero is the supplier's rotation zero.

The automated workflow retains existing placement suggestions as open items.
It refuses to issue a Gerber archive if the routed artifact has errors or fails
the copper-shorts check. Production approval additionally depends on the
existing lab, enclosure and compliance documents.

## Regeneration

```sh
bun install --frozen-lockfile
bun run export:fabrication
bun run check:fabrication
```

The exporter performs a fresh build using the local imported footprints, records
checks, generates BOM/CPL/pinmap/review drawings, and exports Gerbers from that
same circuit JSON. Do not assemble files from different runs or hand-edit
generated CSV, Gerber or manifest files.

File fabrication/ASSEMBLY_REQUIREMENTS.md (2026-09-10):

# Assembly requirements

## Parts and process

Use the full `BOM.csv` for procurement, `BOM-SMT.csv` plus `CPL.csv` for the
surface-mount subset, and `manual-assembly.csv` for the remaining fitted parts.
Mount types are determined from the actual imported copper/hole geometry.
They are not inferred from reference prefixes or descriptions.

The current board uses SMT F1, C1/C4 electrolytics, the remaining small passives,
D1–D6 and U2. J1, RV1, TH1, LCM1, C7, U1 and L1 use plated through-holes. J2
uses SMT contacts and through-hole shell tabs. Agree reflow/selective/hand-solder
sequence and thermal profiles with the assembler; no process is qualified here.

## Orientation and pin checks

- U1: pin 4 is +15 V; pin 3 is isolated GND; pins 1/2 are AC input.
- U2: verify standard `IP6520` marking, pin 1 and exposed pad 9 to GND.
- C1/C4: positive terminal is pin 1. Compare the real case polarity mark with
  `PINMAP.csv` and the native footprint, especially C4's 180° placement.
- D1/D2: cathode is pin 1; D1 goes to VIN_15V, D2 to VBUS_OUT.
- LCM1: pin 1/2 form the line path; pin 4/3 form the neutral path.
- J1: the pin-2 `GND` import alias means AC neutral here, not isolated GND.
- J2: solder the duplicated VBUS/GND/data contacts and shell tabs. SBU1/SBU2
  are intentionally unconnected.

Use `placement-review.csv` to sign off supplier centroids and rotations. Raw
CAD centres and pin locations are supplied to support review, not to claim
supplier calibration.

## Stencil, inspection and mechanics

Review U2 exposed-pad paste segmentation and the four thermal vias for solder
wicking/voiding. Inspect J2's fine-pitch contacts for bridges and its shell
retention. Verify component bodies, solder protrusions, mounting hardware and
cable strain relief against the enclosure and isolation space.

TP1–TP3 are probe pads requiring no assembly part. H1–H4 are NPTH mounting
features; screws, spacers, cord, plug, gland and production enclosure are
external mechanical purchases, not included in the electrical BOM.

Incoming verification of mains-rated parts and U1 documentation follows
[`COMPLIANCE_PLAN.md`](../COMPLIANCE_PLAN.md). Powered first-article checks
follow [`FIRMWARE_BRINGUP.md`](../FIRMWARE_BRINGUP.md) and
[`LAB_VALIDATION_PLAN.md`](../LAB_VALIDATION_PLAN.md).

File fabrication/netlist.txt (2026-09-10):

COMPONENTS:
 - J1: J1, source_component
 - F1: F1, source_component
 - RV1: MOV-14D471K
 - TH1: MF72 5D9
 - LCM1: XRSQ1010-10mH-H
 - C7: 100nF capacitor
 - R3: 1MΩ res1206 resistor
 - R4: 1MΩ res1206 resistor
 - U1: HLK-20M15C
 - C1: 100uF capacitor
 - C2: 100nF cap0603 capacitor
 - D1: SMBJ15A
 - U2: IP6520
 - C3: 2.2uF cap0603 capacitor
 - L1: L1, source_component
 - R1: 2Ω res0603 resistor
 - C6: 1nF cap0603 capacitor
 - C4: 100uF capacitor
 - R2: 0Ω res0603 resistor
 - C5: 100nF cap0603 capacitor
 - D2: SMBJ13A
 - D3: PESD5V0H1BSF
 - D4: PESD5V0H1BSF
 - D5: PESD5V0H1BSF
 - D6: PESD5V0H1BSF
 - J2: J2, source_component
 - TP1: TP1, source_component
 - TP2: TP2, source_component
 - TP3: TP3, source_component

NET: AC_L
  - F1 pin1
  - J1 VIN_POS

NET: AC_L_FUSED
  - TH1 pin1
  - RV1 pin1
  - F1 pin2

NET: AC_L_LIMITED
  - LCM1 pin1
  - TH1 pin2

NET: AC_N
  - LCM1 pin4
  - RV1 pin2
  - J1 GND

NET: X_CAP_BLEED_MID
  - R4 pin1
  - R3 pin2

NET: AC_N_FILTERED
  - U1 AC2
  - R4 pin2
  - C7 pin2
  - LCM1 pin3

NET: AC_L_FILTERED
  - U1 AC1
  - R3 pin1
  - C7 pin1
  - LCM1 pin2

NET: BST
  - C3 pin1 (+)
  - U2 BST

NET: SW
  - R1 pin1
  - L1 pin1 (+)
  - C3 pin2 (-)
  - U2 SW

NET: SNUB
  - C6 pin1 (+)
  - R1 pin2

NET: CC1
  - J2 A5
  - D3 pin1
  - U2 CC1

NET: CC2
  - J2 B5
  - D4 pin1
  - U2 CC2

NET: USB_DP
  - J2 B6
  - J2 A6
  - D5 pin1
  - U2 DP

NET: USB_DM
  - J2 B7
  - J2 A7
  - D6 pin1
  - U2 DM

NET: USB_SHIELD
  - J2 EH3
  - J2 EH4
  - J2 EH1
  - J2 EH2
  - R2 pin1

NET: VIN_15V
  - TP1 pin1
  - U2 VIN
  - D1 pin1 (-)
  - C2 pin1 (+)
  - C1 pin1 (+)
  - U1 VPOS

NET: GND
  - TP2 pin1
  - J2 B1A12
  - J2 A1B12
  - D6 pin2
  - D5 pin2
  - D4 pin2
  - D3 pin2
  - D2 pin2
  - C5 pin2 (-)
  - R2 pin2
  - C4 pin2 (-)
  - C6 pin2 (-)
  - U2 GND
  - D1 pin2 (+)
  - C2 pin2 (-)
  - C1 pin2 (-)
  - U1 VNEG (GND)

NET: VBUS_OUT
  - TP3 pin1
  - J2 A4B9
  - J2 B4A9
  - D2 pin1
  - C5 pin1 (+)
  - C4 pin1 (+)
  - L1 pin2 (-)
  - U2 VOUT

COMPONENT_PINS:
J1 (WJ500V-5.08-2P)
- pin1(VIN_POS, L, LINE): NETS(AC_L)
- pin2(GND, N, NEUTRAL): NETS(AC_N)

F1 (SCT1032T2A250V)
- pin1: NETS(AC_L)
- pin2: NETS(AC_L_FUSED)

RV1 (MOV-14D471K)
- pin1: NETS(AC_L_FUSED)
- pin2: NETS(AC_N)

TH1 (MF72 5D9)
- pin1: NETS(AC_L_FUSED)
- pin2: NETS(AC_L_LIMITED)

LCM1 (XRSQ1010-10mH-H)
- pin1: NETS(AC_L_LIMITED)
- pin2: NETS(AC_L_FILTERED)
- pin3: NETS(AC_N_FILTERED)
- pin4: NETS(AC_N)

C7 (100nF undefined)
- pin1: NETS(AC_L_FILTERED)
- pin2: NETS(AC_N_FILTERED)

R3 (1MΩ res1206)
- pin1(anode, pos, left): NETS(AC_L_FILTERED)
- pin2(cathode, neg, right): NETS(X_CAP_BLEED_MID)

R4 (1MΩ res1206)
- pin1(anode, pos, left): NETS(X_CAP_BLEED_MID)
- pin2(cathode, neg, right): NETS(AC_N_FILTERED)

U1 (HLK-20M15C)
- pin1(AC2, AC_N, N): NETS(AC_N_FILTERED)
- pin2(AC1, AC_L, L): NETS(AC_L_FILTERED)
- pin3(VNEG, GND): NETS(GND)
- pin4(VPOS, VOUT_15V): NETS(VIN_15V)

C1 (100uF undefined)
- pin1(pos): NETS(VIN_15V)
- pin2(neg): NETS(GND)

C2 (100nF cap0603)
- pin1(anode, pos, left): NETS(VIN_15V)
- pin2(cathode, neg, right): NETS(GND)

D1 (SMBJ15A)
- pin1(C, K, CATHODE): NETS(VIN_15V)
- pin2(A, ANODE): NETS(GND)

U2 (IP6520)
- pin1(VOUT): NETS(VBUS_OUT)
- pin2(VIN): NETS(VIN_15V)
- pin3(SW): NETS(SW)
- pin4(BST): NETS(BST)
- pin5(DM): NETS(USB_DM)
- pin6(DP): NETS(USB_DP)
- pin7(CC1): NETS(CC1)
- pin8(CC2): NETS(CC2)
- pin9(GND): NETS(GND)

C3 (2.2uF cap0603)
- pin1(anode, pos, left): NETS(BST)
- pin2(cathode, neg, right): NETS(SW)

L1 (PDMTAT068125-220MLU)
- pin1(anode, pos, left): NETS(SW)
- pin2(cathode, neg, right): NETS(VBUS_OUT)

R1 (2Ω res0603)
- pin1(anode, pos, left): NETS(SW)
- pin2(cathode, neg, right): NETS(SNUB)

C6 (1nF cap0603)
- pin1(anode, pos, left): NETS(SNUB)
- pin2(cathode, neg, right): NETS(GND)

C4 (100uF undefined)
- pin1(pos): NETS(VBUS_OUT)
- pin2(neg): NETS(GND)

R2 (0Ω res0603)
- pin1(anode, pos, left): NETS(USB_SHIELD)
- pin2(cathode, neg, right): NETS(GND)

C5 (100nF cap0603)
- pin1(anode, pos, left): NETS(VBUS_OUT)
- pin2(cathode, neg, right): NETS(GND)

D2 (SMBJ13A)
- pin1(C): NETS(VBUS_OUT)
- pin2(A): NETS(GND)

D3 (PESD5V0H1BSF)
- pin1: NETS(CC1)
- pin2: NETS(GND)

D4 (PESD5V0H1BSF)
- pin1: NETS(CC2)
- pin2: NETS(GND)

D5 (PESD5V0H1BSF)
- pin1: NETS(USB_DP)
- pin2: NETS(GND)

D6 (PESD5V0H1BSF)
- pin1: NETS(USB_DM)
- pin2: NETS(GND)

J2 (TYPE-C-31-M-12)
- pin1(EH2, SH1): NETS(USB_SHIELD)
- pin2(EH1, SH2): NETS(USB_SHIELD)
- pin3(EH4, SH3): NETS(USB_SHIELD)
- pin4(EH3, SH4): NETS(USB_SHIELD)
- pin5(B8, SBU2): NOT_CONNECTED
- pin6(A5, CC1): NETS(CC1)
- pin7(B7, DN2): NETS(USB_DM)
- pin8(A6, DP1): NETS(USB_DP)
- pin9(A7, DN1): NETS(USB_DM)
- pin10(B6, DP2): NETS(USB_DP)
- pin11(A8, SBU1): NOT_CONNECTED
- pin12(B5, CC2): NETS(CC2)
- pin13(A1B12, GND1): NETS(GND)
- pin14(B1A12, GND2): NETS(GND)
- pin15(B4A9, VBUS1): NETS(VBUS_OUT)
- pin16(A4B9, VBUS2): NETS(VBUS_OUT)

TP1
- pin1: NETS(VIN_15V)

TP2
- pin1: NETS(GND)

TP3
- pin1: NETS(VBUS_OUT)

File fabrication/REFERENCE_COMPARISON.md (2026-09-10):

# Reference project comparison

Public file inventories inspected on 2026-09-10 through the tscircuit registry.
The references inform project organization. The charger outputs are generated
from this charger's hardware; no pedometer firmware or fabrication geometry is
copied.

| Project | Inspected version | Release ID |
| --- | --- | --- |
| [techmannih/Bluetooth-pedometer](https://tscircuit.com/techmannih/Bluetooth-pedometer#files) | 1.0.17 | `194fff09-8b0c-491b-9c5b-1df0de933a0b` |
| [imrishabh18/pedometer](https://tscircuit.com/imrishabh18/pedometer#files) | 1.1.3 | `1c7b0745-f622-4f7d-8d72-542968f288fb` |
| [AnasSarkiz/ble-pedometer](https://tscircuit.com/AnasSarkiz/ble-pedometer#files) | 1.0.7 | `94eaf959-3a56-4415-8861-8738e7976a17` |

| Observed files / category | Charger equivalent |
| --- | --- |
| `BOM.csv`, `BOM.md`, `fabrication/BOM.csv` | Root and fabrication BOM plus SMT subset |
| `fabrication/CPL.csv`, placement review | `CPL.csv`, `manual-assembly.csv`, `placement-review.csv` |
| `PINMAP.md`, `fabrication/PINMAP.csv` | `PINMAP.md` and generated complete `PINMAP.csv` |
| `fabrication/Gerbers.zip`, `review/manufacturing/` | Gated `Gerbers.zip` and unpacked `gerbers/` |
| `FABRICATION_NOTES.md`, `docs/fabrication-review.md` | Root fabrication notes and machine-readable check records |
| Assembly requirement documents | `fabrication/ASSEMBLY_REQUIREMENTS.md` |
| `FIRMWARE_BRINGUP.md`, `docs/programming.md`, `CHARGER_BRINGUP.md` | Charger-specific `FIRMWARE_BRINGUP.md` |
| `firmware/src/`, MCU C sources, BLE and sensor drivers | Not applicable to the autonomous IP6520; `firmware/` documents this and supplies a host PDO checker |
| `companion/read_steps.py` | Not applicable: this charger has no step/BLE data stream |
| `POWER_BUDGET.md`, `docs/power-budget.md` | Charger conversion-efficiency and module-headroom calculation |
| `DESIGN_REVIEW.md`, package/datasheet/stock audits | `DESIGN_REVIEW.md`, `PACKAGE_AUDIT.md`, `JLCPCB_PARTS.md` |
| `VALIDATION.md`, `DRC_REPORT.md`, `review/validation.json` | `VALIDATION.md`, `DRC_REPORT.md`, `fabrication/validation.json` and logs |
| Export/check scripts | `scripts/export-fabrication.mjs`, `scripts/check-fabrication.mjs` |
| Schematic, PCB, assembly renders | Both charger schematic sheets, `pcb.svg`, `assembly.svg` |
| Pedometer BGA/RF fanout patches and sensor vendor code | Not applicable to this two-layer charger |

Some reference archives/derived drawings are listed by their own manifests but
are not exposed in their public file inventories. This comparison does not
claim that every reference archive was downloaded or independently validated.

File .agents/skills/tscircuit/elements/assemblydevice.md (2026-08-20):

# `<assembly.device />`

The assembled product: a board together with the mechanical parts built around
it. It is the root a board and its enclosure share, so the enclosure has
something to reference.

## Example

```tsx
import { assembly, enclosure } from "tscircuit"

export default () => (
  <assembly.device name="widget">
    <board name="B1" width="52mm" height="36mm">
      {/* parts */}
    </board>
    <enclosure.fdm.box boardRef=".B1" />
  </assembly.device>
)
```

Use it when a design has anything beyond the bare PCB. A board on its own does
not need one.

## Props

Commonly used: `name`

## References

- Props: [AssemblyDeviceProps](https://github.com/tscircuit/props/blob/main/lib/assembly/device.ts)
- See also: [`<enclosure.fdm.box />`](./enclosurefdmbox.md), [`<board />`](./board.md)

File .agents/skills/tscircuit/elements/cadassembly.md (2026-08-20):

# `<cadassembly />`

A CAD assembly is a collection of cad models and constraints to "put together" a component.

## Example

```tsx
export default () => (
  <board width="10mm" height="10mm">
    <chip
      name="J1"
      cadModel={
        <cadassembly>
          <cadmodel
            positionOffset={{ x: 0, y: -4, z: 0 }}
            rotationOffset={{ x: 0, y: 0, z: 0 }}
            modelUrl="https://modelcdn.tscircuit.com/jscad_models/pinrow4.glb"
          />
          <cadmodel
            positionOffset={{ x: 0, y: 4, z: 0 }}
            rotationOffset={{ x: 0, y: 0, z: 0 }}
            modelUrl="https://modelcdn.tscircuit.com/jscad_models/pinrow4.glb"
          />
        </cadassembly>
      }
    />
  </board>
)
```

## Props

Commonly used: `originalLayer`, `children`, `name`, `footprint`, `connections`

## References

- Props: [CadAssemblyProps](https://github.com/tscircuit/props#cadassemblyprops-cadassembly)
- Source: [lib/components/cadassembly.ts](https://github.com/tscircuit/props/blob/main/lib/components/cadassembly.ts)
- Local docs: [docs/docs/elements/cadassembly.mdx](../docs/docs/elements/cadassembly.mdx)

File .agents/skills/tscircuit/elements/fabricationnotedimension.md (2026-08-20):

# `<fabricationnotedimension />`

Dimension callout drawn on the fabrication layer.

## Example

```tsx
export default () => (
  <board width="20mm" height="15mm">
    <fabricationnotedimension
      from={{ x: -4, y: 0 }}
      to={{ x: 4, y: 0 }}
      fontSize={1.2}
      arrowSize={0.8}
    />
  </board>
)
```

## Props

Commonly used: `from`, `to`, `text`, `offset`, `font`, `fontSize`, `color`, `arrowSize`

## References

- Props: [FabricationNoteDimensionProps](https://github.com/tscircuit/props#fabricationnotedimensionprops-fabricationnotedimension)
- Source: [lib/components/fabrication-note-dimension.ts](https://github.com/tscircuit/props/blob/main/lib/components/fabrication-note-dimension.ts)

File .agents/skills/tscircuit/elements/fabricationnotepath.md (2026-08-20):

# `<fabricationnotepath />`

Polyline/path annotation on the fabrication layer.

## Example

```tsx
export default () => (
  <board width="20mm" height="20mm">
    <fabricationnotepath
      strokeWidth={0.3}
      route={[
        { x: -5, y: 0 },
        { x: 0, y: 5 },
        { x: 5, y: 0 },
      ]}
    />
  </board>
)
```

## Props

Commonly used: `pcbLeftEdgeX`, `pcbRightEdgeX`, `pcbTopEdgeY`, `pcbBottomEdgeY`, `pcbX`, `pcbY`, `pcbOffsetX`, `pcbOffsetY`

## References

- Props: [FabricationNotePathProps](https://github.com/tscircuit/props#fabricationnotepathprops-fabricationnotepath)
- Source: [lib/components/fabrication-note-path.ts](https://github.com/tscircuit/props/blob/main/lib/components/fabrication-note-path.ts)

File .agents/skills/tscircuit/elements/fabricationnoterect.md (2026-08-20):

# `<fabricationnoterect />`

Highlight fabrication callouts and assembly regions with rectangular annotations on the fabrication layer.

## Example

```tsx
export default () => (
  <board width="28mm" height="20mm">
    <resistor name="R1" resistance="1k" footprint="0603" pcbX={-6} pcbY={-2} />
    <capacitor name="C1" capacitance="1uF" footprint="0603" pcbX={-2} pcbY={2} />
    <fabricationnotetext
      text="Install last"
      pcbX={5}
      pcbY={2}
      anchorAlignment="bottom_left"
      fontSize="1.4mm"
    />
    <fabricationnoterect
      pcbX={0}
      pcbY={0}
      width={18}
      height={12}
      strokeWidth={0.3}
      color="#2563eb"
      hasStroke
    />
  </board>
)
```

## Props

Commonly used: `width`, `height`, `strokeWidth`, `isFilled`, `hasStroke`, `isStrokeDashed`, `color`, `cornerRadius`

## References

- Props: [FabricationNoteRectProps](https://github.com/tscircuit/props#fabricationnoterectprops-fabricationnoterect)
- Source: [lib/components/fabrication-note-rect.ts](https://github.com/tscircuit/props/blob/main/lib/components/fabrication-note-rect.ts)
- Local docs: [docs/docs/footprints/fabricationnoterect.mdx](../docs/docs/footprints/fabricationnoterect.mdx)

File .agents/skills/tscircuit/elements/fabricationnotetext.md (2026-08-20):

# `<fabricationnotetext />`

The `<fabricationnotetext />` element adds fabrication layer callouts and build notes for assemblers.

## Example

```tsx
export default () => (
  <board width="24mm" height="18mm">
    <resistor name="R1" resistance="10k" footprint="0402" pcbX={-5} pcbY={0} />
    <led name="D1" footprint="0603" pcbX={5} pcbY={0} />
    <fabricationnotetext
      text="Install connector last"
      pcbX={0}
      pcbY={6}
      fontSize="1.6mm"
      anchorAlignment="top_left"
      color="#d97706"
    />
  </board>
)
```

## Props

Commonly used: `text`, `anchorAlignment`, `font`, `fontSize`, `color`, `name`, `footprint`, `connections`

## References

- Props: [FabricationNoteTextProps](https://github.com/tscircuit/props#fabricationnotetextprops-fabricationnotetext)
- Source: [lib/components/fabrication-note-text.ts](https://github.com/tscircuit/props/blob/main/lib/components/fabrication-note-text.ts)
- Local docs: [docs/docs/footprints/fabricationnotetext.mdx](../docs/docs/footprints/fabricationnotetext.mdx)

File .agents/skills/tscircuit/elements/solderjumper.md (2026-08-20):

# `<solderjumper />`

Small pads that can be cut or bridged with solder for configuration options.

## Example

```tsx
export default () => (
  <solderjumper name="SJ1" footprint="solderjumper2_bridged12" bridgedPins={[["1","2"]]} />
)
```

## Props

Commonly used: `bridgedPins`, `bridged`, `name`, `footprint`, `connections`

## References

- Props: [SolderJumperProps](https://github.com/tscircuit/props#solderjumperprops-solderjumper)
- Source: [lib/components/solderjumper.ts](https://github.com/tscircuit/props/blob/main/lib/components/solderjumper.ts)
- Local docs: [docs/docs/elements/solderjumper.mdx](../docs/docs/elements/solderjumper.mdx)

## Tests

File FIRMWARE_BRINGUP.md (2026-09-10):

# Controller and board bring-up

U2 operates autonomously; no firmware flashing step exists in this revision.
The [`firmware/`](firmware/README.md) folder contains the expected controller
profile and a utility for checking decoded protocol captures.

## Traceability and configuration

Record PCB/source revision, the fabrication manifest hash, U1 and U2 markings,
component substitutions, sample serial number and test equipment. Confirm that
U2 is `IP6520`, LCSC `C7433861`, standard non-PPS. Neither the USB-C connector nor
the test points provide a programming port.

## Interfaces and observation points

| Interface | Mapping / expected role |
| --- | --- |
| J1 pin 1 | AC line (`AC_L`) |
| J1 pin 2 | AC neutral (`AC_N`); imported alias `GND` here does **not** mean isolated ground |
| U1 pin 4 / pin 3 | Isolated +15 V / GND |
| TP1 / TP2 | Isolated `VIN_15V` / GND |
| TP3 / TP2 | USB `VBUS_OUT` / GND |
| U2 pin 7 / pin 8 | CC1 / CC2 to J2 |
| U2 pin 6 / pin 5 | D+ / D− charging-protocol signals to J2 |
| J2 shell | `USB_SHIELD`, connected to GND through R2 = 0 Ω |

[`fabrication/PINMAP.csv`](fabrication/PINMAP.csv) is the generated complete
pin/net/PCB-position map, including the intentionally unconnected J2 SBU pins.

## Verification sequence

1. Check assembled BOM, polarity, solder joints, U2 exposed-pad soldering,
   connector pinout and spacing against the generated assembly drawing.
2. Use the qualified-lab setup described in
   [`LAB_VALIDATION_PLAN.md`](LAB_VALIDATION_PLAN.md) for powered testing.
   Record the actual isolated 15 V rail and attached-sink default 5 V behavior.
3. Capture Source_Capabilities for both cable orientations. Compare the decoded
   record using `bun run check:pdos <capture.json>`.
4. Exercise the three PDOs with the lab's PD sink/electronic load, retaining
   voltage/current, ripple, transition, dropout and protection observations.
5. Complete the 18 W closed-enclosure thermal and input-power tests. In
   particular, validate 12 V / 1.5 A from the actual 15 V module output.

No measured hardware results are included. See [`POWER_BUDGET.md`](POWER_BUDGET.md)
for calculated headroom and [`firmware/VALIDATION.md`](firmware/VALIDATION.md)
for evidence still to collect.

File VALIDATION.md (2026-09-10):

# Validation and reproducibility

Run `bun run export:fabrication` to build and record a fresh review package.
Then run `bun run check:fabrication` to verify source hashes, file hashes, BOM
coverage, SMT/manual membership, placement coordinates, pin-map coverage,
both schematic sheets and Gerber ZIP integrity/content.

`fabrication/validation.json` is the machine-readable record for the generated
artifact, with timestamp, circuit hash, statuses and log paths. The source
manifest includes documentation, circuit imports, scripts, firmware targets,
package.json and bun.lock. Changes require regeneration.

## What the checks mean

| Check | Scope |
| --- | --- |
| Typecheck | TypeScript source consistency |
| Netlist | Declared connections and netlist diagnostics |
| Schematic placement | Readability/layout suggestions; exit 0 can still include suggestions |
| PCB placement | Placement DRC and routing-orientation suggestions |
| Build | Fresh circuit using locked local imports; supplier parts engine disabled |
| Routing | `@tscircuit/checks` routing checks on the exact exported circuit |
| Shorts | Gerber-derived copper bitmap check, both layers, CLI default resolution |
| Fabrication integrity | Export data, source/ZIP hashes and cross-file consistency |
| PDO utility | Comparison of supplied decoded Source_Capabilities records only |

No passing hardware results or supplier approvals are claimed. The existing
placement suggestions are retained as review items. `check:fabrication`
passing means the package is internally consistent; use `validation.json`
to see CAD review items and separate physical release requirements.

## Toolchain

Requires Bun and the `zip`/`unzip` command-line tools (available on macOS and
commonly installed on Linux). Install dependencies with
`bun install --frozen-lockfile`. Exact tool versions used for each generation
are in `fabrication/manifest.json`.

The current script supports one 110 × 60 mm, two-layer board and generates a
sheet SVG for each declared schematic sheet. It does not upload files, place
orders, modify controller firmware, or run remote supplier calibration.

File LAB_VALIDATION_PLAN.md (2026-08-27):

# Lab validation plan

All mains tests must be performed by qualified personnel using an accredited laboratory or an appropriately equipped safety lab. This document defines evidence to obtain; it is not an instruction for unprotected bench testing.

## 1. Sample and document control

- Record PCB revision, Gerber hash, exact BOM/lot codes, AC/DC module date code, the full U2 top marking and confirmation that it is the standard non-PPS IP6520, enclosure resin lot, cord/plug and label revision.
- Compare samples against schematic, PCB, critical-component list and mechanical drawings.
- Photograph the unopened product, internal construction, spacings, wiring, anchorage and markings.

## 2. Construction and safety review

- Confirm Class II construction, insulation system, primary-to-SELV creepage/clearance, PCB material group, pollution degree and altitude assumptions.
- Measure the real assembled spacings, including component bodies, leads, solder fillets, mounting hardware, enclosure ribs and connector openings—not only nominal CAD separation.
- Evaluate fuse breaking capacity and coordination, MOV failure/thermal risk, X2 capacitor and bleeder ratings, internal wire ratings and polarity.
- Perform accessibility/probe, cord anchorage, pull/twist, fastener retention, impact/drop and enclosure material/heat assessments required by the applicable standard.

## 3. Electrical safety and performance

- Input current/power, no-load consumption, end-to-end efficiency and output regulation across declared input limits and every supported PDO.
- Dielectric-strength, insulation-resistance and touch/leakage-current tests using lab-selected levels and sequences.
- Output current limit, short circuit, overload, repeated startup and recovery.
- Verify 5 V default behavior before PD negotiation and all supported 5 V, 9 V and 12 V transitions under static and dynamic load.
- Verify that Source_Capabilities contains only the 5 V / 3 A, 9 V / 2 A, and 12 V / 1.5 A fixed-supply PDOs, with no PPS APDO, and that unsupported requests are rejected safely.
- Characterize 12 V / 1.5 A specifically with U2 supplied from the real 15 V module rail at its measured minimum and maximum voltage. Include startup, load steps, cable drop, dropout/regulation margin and protection behavior because the datasheet's 12 V electrical-characteristic point uses a 24 V input.
- Test cable attach/detach, cable orientation, unsupported requests, brownout/restart and representative phones/cables in addition to protocol-analyzer tests.

## 4. Thermal and abnormal conditions

- Temperature rise at low and high declared mains voltage, no load, typical load and continuous 18 W at both 9 V / 2 A and 12 V / 1.5 A in the final closed enclosure.
- Demonstrate that U1 remains within its 15 V / 1.333 A output rating and temperature derating limits while supplying converter losses at 18 W USB output; the nameplate ratings alone are not evidence of adequate margin.
- Record ambient, stabilization criterion and temperatures of U1, U2, L1, fuse, MOV, NTC, C7, connectors, PCB, internal wiring and enclosure touch surfaces.
- Apply the standard's relevant single-fault/abnormal conditions, blocked ventilation, output short/overload and component fault simulations.
- Inspect for charring, insulation damage, displaced parts, loss of protective function or unsafe restart after each test.

## 5. EMC, immunity and port robustness

- Conducted and radiated emissions on representative mains leads, loads, USB cables and enclosure configuration.
- Applicable ESD, electrical fast transient, surge, RF immunity, voltage dips/interruptions and magnetic-field tests selected by the lab for the destination market.
- Confirm fuse/MOV coordination after surge sequences and inspect protective parts for degradation.
- Repeat essential output and PD behavior after immunity exposure.

## 6. USB-IF program

- Use an authorized USB-IF independent test lab and the current applicable Type-C and USB-PD compliance test specifications.
- Exercise every supported PDO, source-capability message, role behavior, CC orientation, error recovery and relevant USB 2.0 path requirement.
- Resolve all waivers/issues, obtain the TID/listing and approve logo/claim usage before packaging release.

## 7. Production end-of-line controls

The accredited lab and safety engineer should approve limits and fixtures for:

- visual/traceability and critical-component verification;
- dielectric/leakage or the permitted production equivalent;
- output voltage/current-limit and PD handshake checks;
- insulation/fixture interlocks, calibration, failure segregation and retained records.

## Release gate

Release requires passing reports tied to the final hardware/enclosure revision, closure of every nonconformity, approved product markings/instructions and written disposition for all deviations. A clean CAD build or successful bench charge does not satisfy this gate.

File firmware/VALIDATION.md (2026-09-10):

# Controller verification status

| Item | Status |
| --- | --- |
| Flashable application / toolchain | Not applicable: no programmable MCU on this board |
| Expected PDO declaration | Design target in `expected-pdos.json` |
| Host checker | `bun run check:pdos <capture.json>`; decoded records only |
| Actual Source_Capabilities capture | Not supplied |
| Real 15 V to 12 V / 1.5 A load test | Not supplied |
| Continuous full-load thermal test | Not supplied |
| Cable orientation, attach/detach and fault recovery | Not supplied |

Record actual sample IDs and analyzer log filenames before changing hardware
test statuses. A passing fixture used to exercise the host checker is not a
hardware pass. Full test requirements are in
[`LAB_VALIDATION_PLAN.md`](../LAB_VALIDATION_PLAN.md).

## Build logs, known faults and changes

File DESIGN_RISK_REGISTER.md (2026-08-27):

# Design risk register

| Risk | Current control | Residual action / release gate |
| --- | --- | --- |
| Lethal mains contact | Primary zone, 8 mm copper keepout, warning marks | Final enclosure accessibility, wiring, dielectric and construction tests must pass |
| Fire during surge or abnormal load | Fuse, MOV, NTC, encapsulated module | Lab must validate fuse/MOV coordination, fault behavior, flame containment and real component approvals |
| Isolation approval assumed from U1 | Encapsulated module replaces custom transformer | Obtain current supplier certification evidence and test the complete end product; module evidence does not transfer automatically |
| PCB spacing misunderstood | Conservative 8 mm copper corridor | Lab must calculate and measure required creepage/clearance for actual standard, voltage, material group, pollution degree and altitude |
| Unsafe mains cable entry | Cable aperture/terminal model provided | Production cord, plug, gland and independent strain relief must be specified and mechanically tested |
| FDM enclosure used as finished housing | Model is explicitly marked fit-check only | Release only injection-molded or otherwise lab-approved flame-retardant production construction |
| Surge suppressor end-of-life | 300 VAC MOV behind fuse | Confirm energy rating, fault mode, thermal/fire behavior and surge life in accredited testing |
| Limited AC/DC-to-USB power headroom | 15 V / 1.333 A module, synchronous buck SoC and isolated-side test points | Measure input power, efficiency, regulation and closed-enclosure temperature rise at every 18 W operating point across mains/ambient limits; revise the rating or architecture if U1 derating or converter losses exhaust margin |
| 12 V / 1.5 A operation from a 15 V rail | 15 V is within the IP6520 input range and the design follows the reference power stage | Validate dropout, startup, load transients, regulation and protection on hardware; the datasheet's 12 V electrical-characteristic point is at 24 V input |
| USB overvoltage/ESD | VBUS TVS and CC/data ESD clamps | Validate clamp behavior, PD transitions, ESD and connector/cable cases on hardware |
| Incorrect PD marketing | Standard IP6520 source-PDO design; no PPS claim | Confirm the exact non-PPS U2 marking and verify 5 V / 3 A, 9 V / 2 A, and 12 V / 1.5 A source capabilities with a protocol analyzer; no certified logo before TID |
| Supplier substitution | Exact MPNs and supplier IDs captured; other IP6520 variants explicitly excluded | Approved-vendor list, incoming inspection and certification-impact review for every change |
| CAD success mistaken for compliance | Automated netlist/placement/short checks | Physical electrical-safety, EMC, thermal, mechanical and USB tests remain mandatory |

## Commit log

2026-08-20 add charger
2026-08-26 Feat/18w usb c pd wall charger (#1)
    * up
    * up
    * up
    [enclosure-fit-check.scad]
2026-08-26 Update 3D snapshot with full charger assembly (#2)
2026-08-26 Fix/update 3d snapshot (#3)
    * Update 3D snapshot with full charger assembly
    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
